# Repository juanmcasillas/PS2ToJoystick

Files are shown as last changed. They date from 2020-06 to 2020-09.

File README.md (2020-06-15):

# PS2ToJoystick

After trying to connect my old [EMS PS2 to PC adapter](http://www.hkems.com/product/ps2/ps2-usb2.htm) in Windows 10 without success, because there are no drivers available for Windows 10 x64; and the provided driver from Microsoft doesn't show the controller, I build this small PS2 to PC adapter, using an **arduino micro**, a **PS2 female connector** and some wire. And here you are!, **PS2ToJoystick** !.

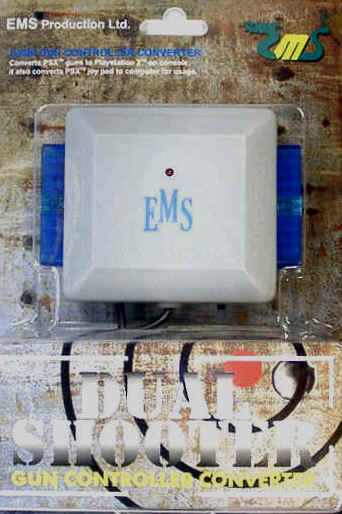
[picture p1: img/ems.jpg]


## Table Of Contents

1. [Project Features](#project-features)
2. [Part List](#part-list)
3. [Software](#software)
    1. [Arduino Setup](#arduino-setup)
    2. [Testing](#testing)
    3. [Multi](#multi)
4. [Electronics](#electronics)
    1. [Wiring](#wiring)
5. [Box Enclosure](#box-enclosure)
6. [X360 Controller](#x360-controller)

## Project Features

This project provides:

1. The hardware diagram to connect the PS2 connector to the arduino micro.
2. The software to map the PS2 Dualshock 2 gaming pad buttons and axis, to PC Joystick buttons.
3. The STL to 3D print a simple box to enclosure all.
4. The documentation to map the excellect [X360ce driver](https://github.com/x360ce/x360ce/releases) so the arduino is shown as an X360 PC Controller.

**NOTE**: Rumble (aka vibration) is not supported.

## Part List

1. Arduino Pro Micro clone (**ATmega32U4**) from [amazon](https://www.amazon.es/gp/product/B01MTU9GOB/.ref=ppx_yo_dt_b_asin_title_o04_s00?ie=UTF8&psc=1)
2. A female PS2 Dualshock 2 connector. I get one unironing it from the old EMS PS2 to PC Adapter.
3. Some wire.
4. A 3D Printer if you want to print the case.

## Software

The concept is very simple: map the PS2 Dualshock 2 buttons to an HID compatible device (joystick) so windows handles it with the standard driver. Arduino Leonardo (Micro) supports USB impersonation, so we can configure it as a Joystick, so problem solved.

My work is based on [this article](https://www.instructables.com/id/PS2-Wire-Controller-and-Arduino-control-LEDs/) and the excellect library created by [Bill Porter](http://www.billporter.info/2010/06/05/playstation-2-controller-arduino-library-v1-0/): [PS2X_lib](https://github.com/madsci1016/Arduino-PS2X/tree/master/PS2X_lib). A deep work on button protocol handling can be found [here](https://store.curiousinventor.com/guides/PS2). We need also the [Joystick Library](https://github.com/MHeironimus/ArduinoJoystickLibrary).

### Arduino Setup

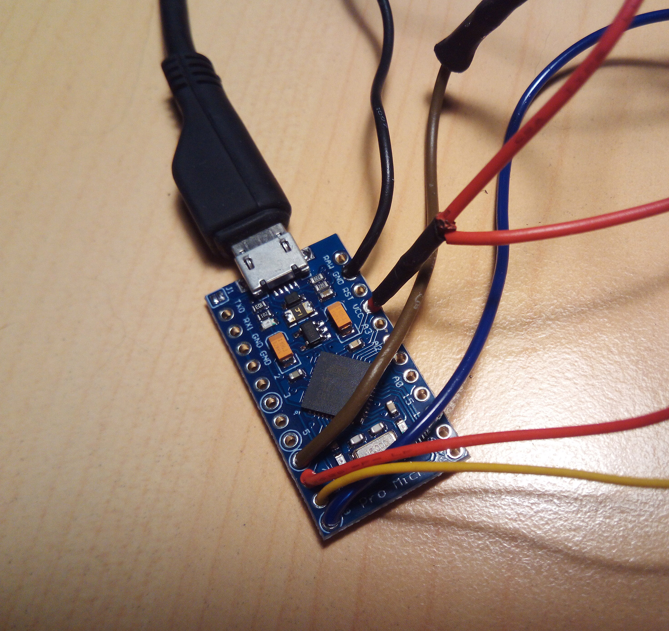
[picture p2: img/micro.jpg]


1. Download [PS2X_lib](https://github.com/madsci1016/Arduino-PS2X/tree/master/PS2X_lib) and install it in arduino libraries folder.
2. Download [ArduinoJoystickLibrary](https://github.com/MHeironimus/ArduinoJoystickLibrary) and install it in arduino libraries folder.
3. The Arduino Pro Micro selected uses an **ATmega32U4** microprocessor, so we have to choose in the board list
**Arduino Leonardo**. 
4. Select the USB port
5. Flash the `ps2joystick/ps2joystick.ino` sketch as usual.

NOTE: See [Multi](#multi) for an alternate sketch that support Keyboard & Joystick Handling at the same time.

### Testing

Just connect your Arduino Micro Clone in the PC with Windows 10, and open `Game Controllers`, you should have something like the following window:

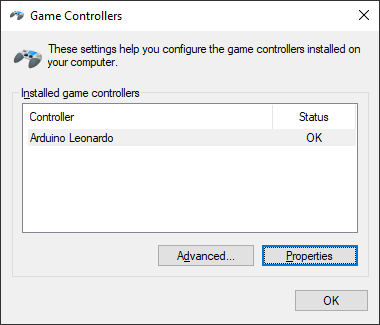
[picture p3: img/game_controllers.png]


Then click ond Properties, and check the buttons:

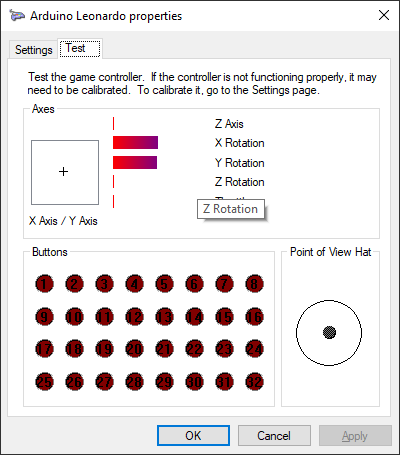
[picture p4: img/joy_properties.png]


* Left analog stick is mapped to X/Y Axis.
* Right analog stick is mapped to X/Y Rotation.

Button Mapping (on X360ce, we have to add '1' to the ID, see below)

|Name |Id |
|---|---:|
|JOY_CROSS |0 |
|JOY_CIRCLE |1 |
|JOY_SQUARE |2 |
|JOY_TRIANGLE |3 |
|JOY_L1 |4 |
|JOY_L2 |5 |
|JOY_L3 |6 |
|JOY_R1 |7 |
|JOY_R2 |8 |
|JOY_R3 |9 |
|JOY_SELECT |10 |
|JOY_START |11 |
|JOY_PAD_UP |12 |
|JOY_PAD_DOWN |13 |
|JOY_PAD_LEFT |14 |
|JOY_PAD_RIGHT |15 |

So you have a functional PS2 Dualshock 2 gaming pad working on your Windows 10, as a Joystick!. If you want to play modern games with the pad, you should read the section below [X360 Controller](#x360-controller)

### Multi

You can manage multiple HID devices from the same arduino Leonardo. Just load the required libraries, and work on. I need this support for mapping the [r6Pedals](https://github.com/juanmcasillas/r6pedals) project,
so I use only one arduino to handle the joystick and the custom button keyboards. instead flashing `ps2joystick/ps2joystick.ino` sketch, flash `ps2multi/ps2multi.ino`. This sketch maps:

|Arduino PIN |color |key |
|---|---|---:|
|4 |yellow  |e |
|5 |green |q |
|gnd |black | |
|gnd |black | |

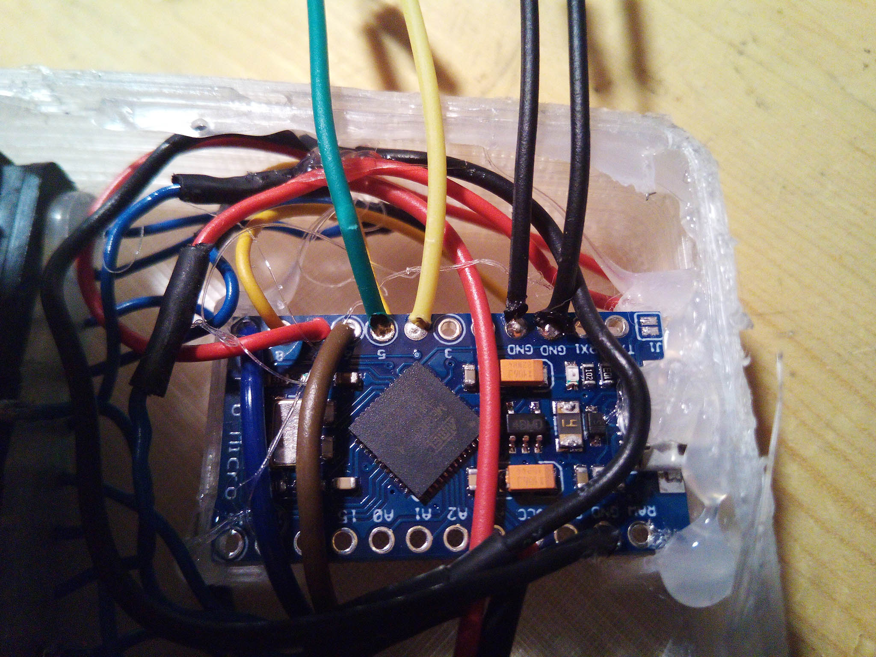
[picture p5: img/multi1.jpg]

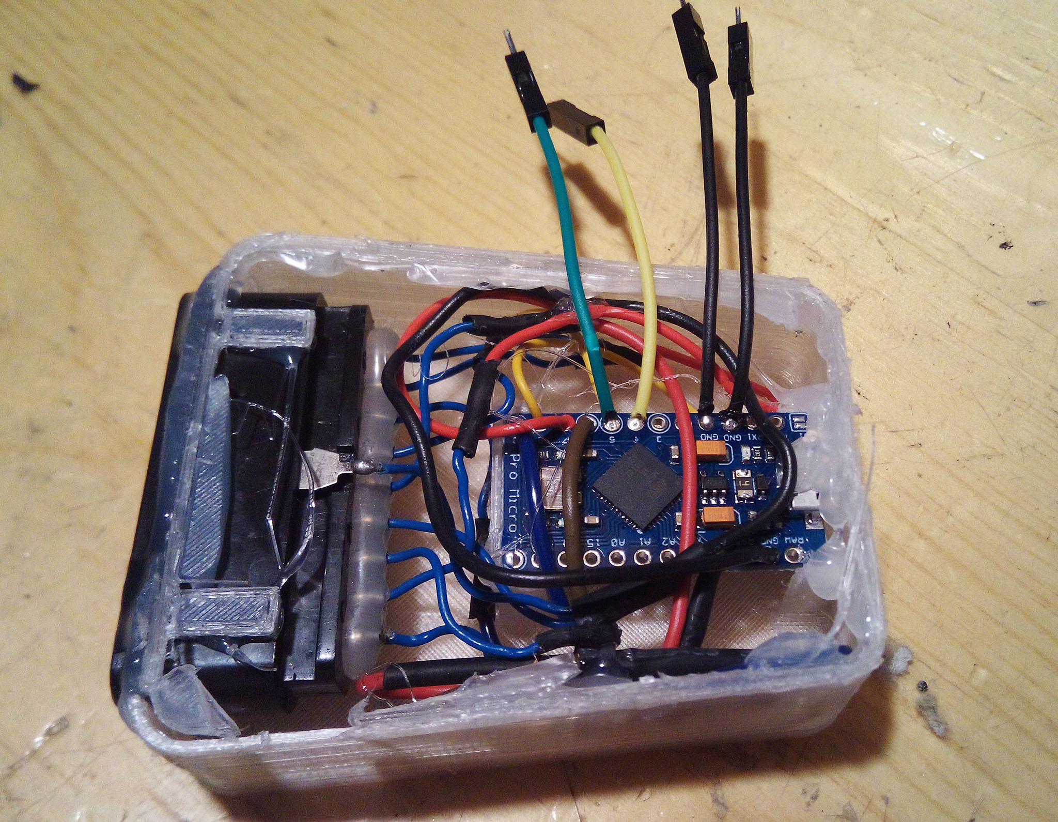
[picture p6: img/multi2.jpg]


## Electronics

Easy electronics. Just solder some wires (use pins if you want) following the next diagram

### Wiring

Female Socket (the opposite to DualShock 2 connector) (looking from FRONT)
```
\-------------------------/
 \ 1 2 3   4 5 6   7 8 9 /
  \---------------------/
```

|Dualshock PIN |color |function | arduino PIN|
|---|---|---|---:|
|1 |brown |DATA | (with pullup resistor 4.7KOhm) 6|
|2 |orange  |COMMAND  | 7|
|3 |grey |VIBRATION| |
|4 |black |GROUND | GND|
|5 |red |VCC | VCC|
|6 |yellow  |SELECT | 8|
|7 |blue |CLOCK | 9|
|8 |white |UNKNOWN  | |
|9 |green |ACK | |

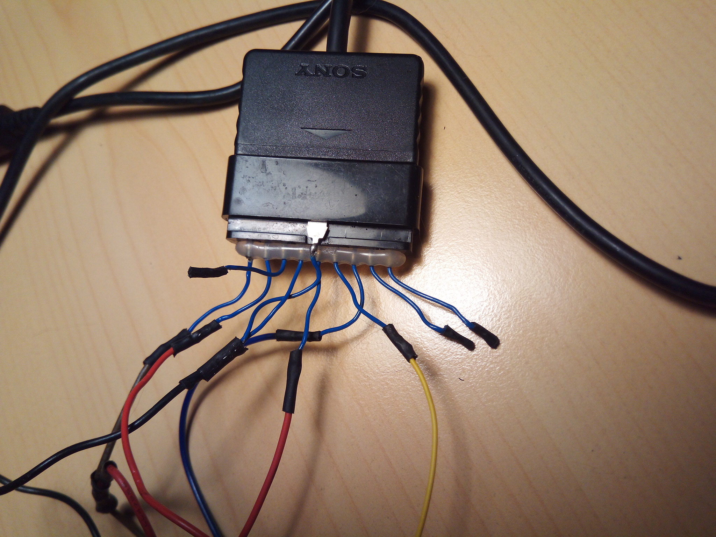
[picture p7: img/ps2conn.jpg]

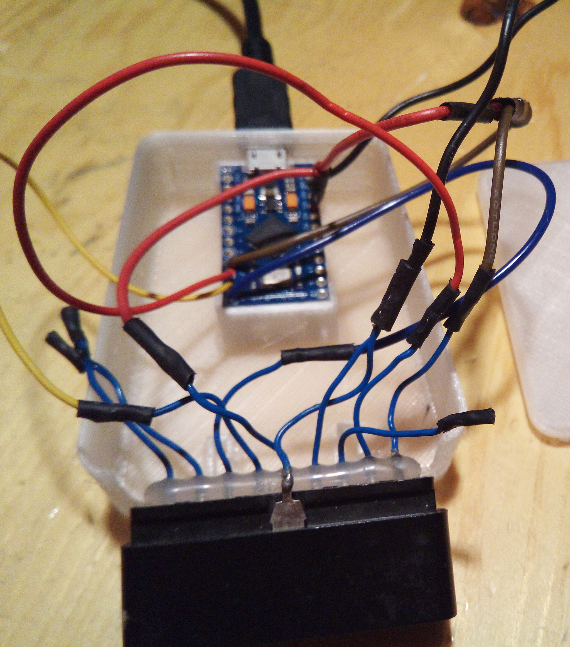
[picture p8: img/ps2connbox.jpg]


On **DualShock 2 PIN 1**, we need a pull up Resistor. This is the wiring diagram for that PIN:

```
                                ARDUINO PIN 6
                                    |
                                    |
 VCC -------------[ R 4.7KOhm ]-----+
                                    |
                                    |
                                DUALSHOCK 2 PIN 1 (BROWN)
```

In this picture, you can see the pull up resistor on the left side.
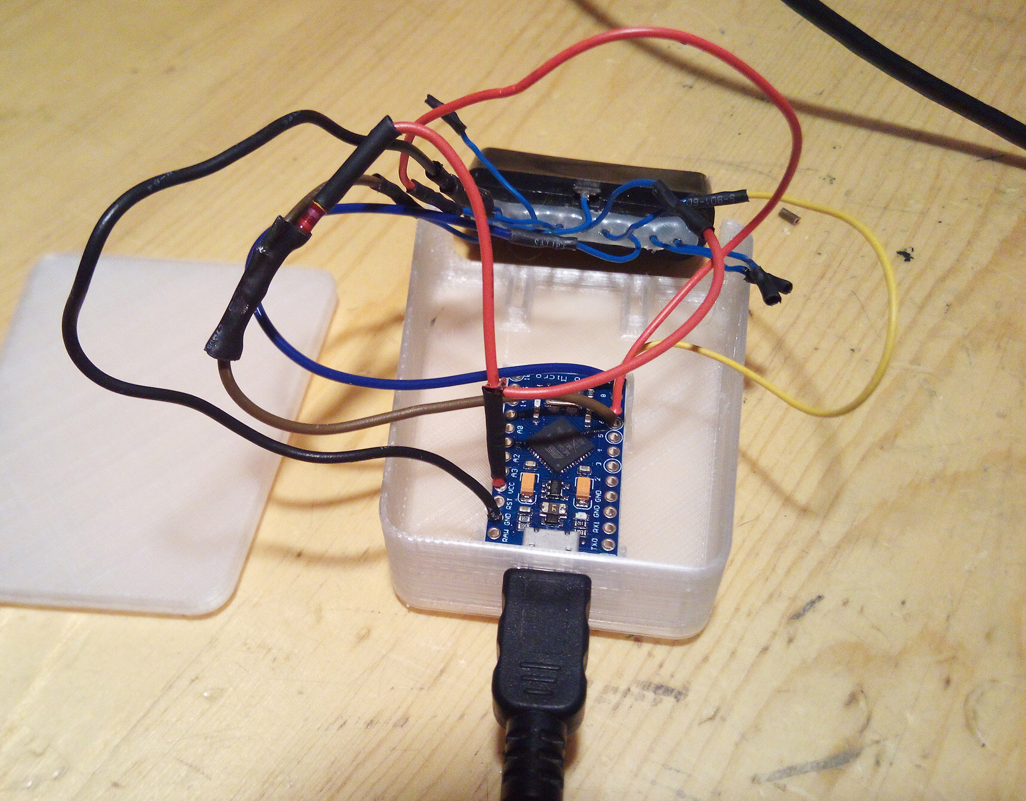
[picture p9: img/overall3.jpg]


## Box Enclosure

I provide a simple STL `3dprint/box.stl` file for the box enclosure, if you want to print it. The STL are ready positioned in the "right" way to be printed, so just print them as is. I use a Ender-3 Pro with Marlin Firwmare, and PLA, and get good results. It tooks about **2 hours 30 minutes** to print. I use CURA for slicing with the following major configuration settings:

|Variable |Value |
|---|---:|
|Layer Height| 0.21|
|Initial Layer Height| 0.32|
|Wall Thickness| 0.88|
|Wall Line count| 3|
|Top/Bottom Thickness| 0.92|
|top Thickness| 0.92|
|Top Layers| 5|
|bottom Thickness| 0.92|
|bottom Layers| 5|
|Top/Bottom pattern| lines|
|Horizontal expansion| 0|
|Infill density| 60%|
|Infill pattern| grid|
|Printing temperature| 190|
|Printing temperature initial layer| 195|
|Build plate temperature| 55|
|Build plate temperature initial layer| 75|
|Initial Layer flow| 100|
|Enable retraction| Checked|
|Retraction Distance| 6.5|
|Retraction Speed| 50|
|Print Speed| 50|
|Infill Speed| 50|
|Wall speed| 25|
|Top/Bottom speed| 25|
|Travel Speed| 150|
|Initial Layer Print Speed| 15|
|Initial Layer Travel Speed| 30|
|Combing mode| All|
|Avoid Supports when travelling| checked|
|Z Hop when retracted| checked|
|Enable Print cooling| checked|
|Fan Speed| 100|
|Initial Fan Speed| 0|
|Regular Fan Speed at Height| 0.72|
|Regular Fan Speed at Layer| 3|
|Generate Support| Checked|
|Support Placement| Everywhere|
|Support Overhang Angle| 47|
|Support Pattern| ZigZag|
|Support Density| 20|
|Support Z Distance| 0.2|
|Suport X/Y Distance| 0.88|
|User Towers| unchecked|
|Build plate adhesion type| None|
|Surface mode| Normal|
|Enable Bridge Settings| Checked|

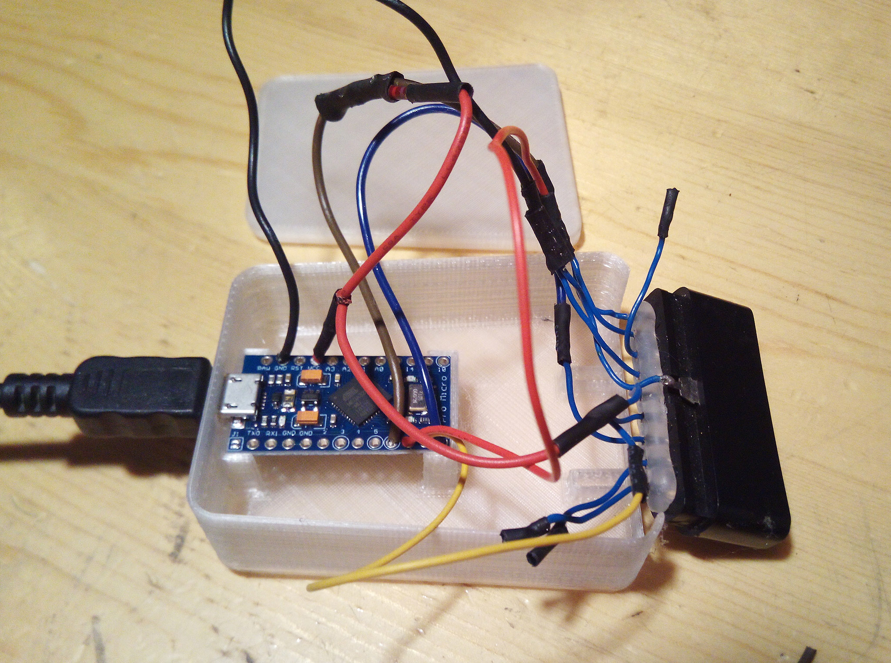
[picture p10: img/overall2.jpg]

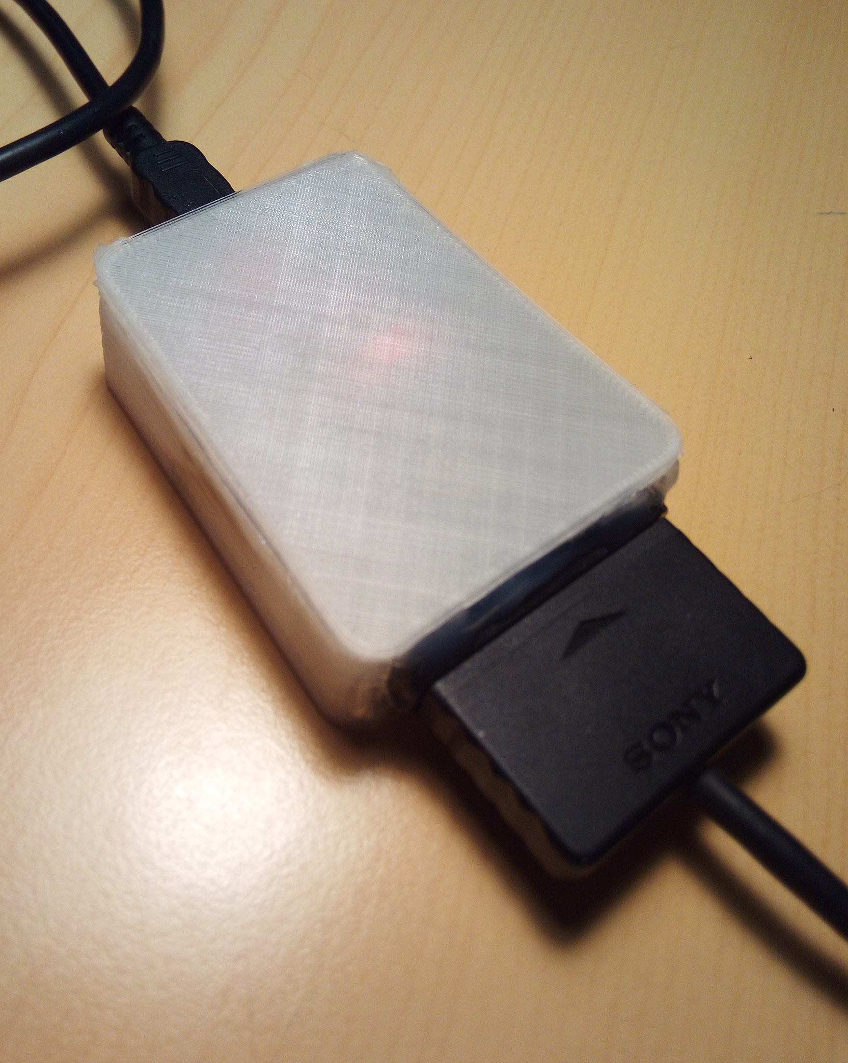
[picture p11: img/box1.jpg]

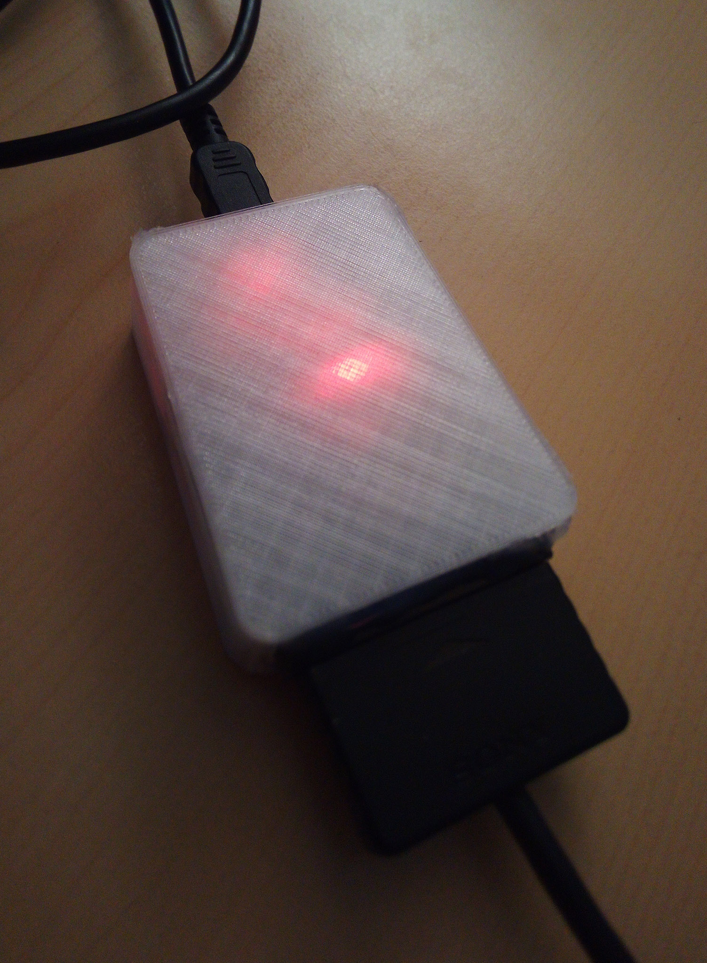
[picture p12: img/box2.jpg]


## X360 Controller

[X360ce](https://github.com/x360ce/x360ce) is a XBox 360 Contoller emulator: 

>"Xbox 360 Controller Emulator" allows your controller (gamepad, joystick, wheel, etc.) 
>to function as an Xbox 360 controller. For example, it lets you play games such 
>as "Grand Theft Auto" (GTA) or "Mafia II" using a Logitech Wheel.

We need to use the NEW version [alpha](https://github.com/x360ce/x360ce/releases/tag/4.10.0.0), no the stable one (they are very different) so [get the driver](https://github.com/x360ce/x360ce/releases/download/4.10.0.0/x360ce.zip) and install it.

I use this [excellect tutorial](https://steamcommunity.com/sharedfiles/filedetails/?id=875960196) to figure how to install it (this tutorial is for the old version). But the new version of X360ce requires a [sighly modified installation steps](https://github.com/x360ce/x360ce/wiki/Beta-Testing):

From their website:

>There is no need to place x360ce.exe inside the game folder. You can keep single copy of executable at one place (for >example: C:\Program Files\x360ce\x360ce.exe), because same virtual "Xbox 360 Controller" will be visible for all games >in Windows.

>Do not close "Xbox 360 Controller Emulator" during the game, just minimize it in order to reduce CPU use.

>Make sure your game is set to use XInput Devices. For example, in "Tom Clancy's Ghost Recon Wildlands" you have to set >OPTIONS -> CONTROLLER -> ENABLE CONTROLLER: ONLY GAMEPADS

### Install instructions (from their website):

1. Download latest Xbox 360 Controller Emulator (same file for 32-bit and 64-bit Windows) from: x360ce [4.x.x.x - Releases Page](https://github.com/x360ce/x360ce/releases)
2. Extract ZIP file and launch `x360ce.exe` file.
3. Enabling Virtual Drivers:
    1. `[Issues]` tab will start blinking it Virtual Drivers are missing.
    2. Press `[Issues]` tab and hit `[Install]` button to install Virtual Controller Drivers.
4. Mapping DirectInput Device:
    1. Connect your DirectInput Device to PC
    2. Select `[Controller 1]` tab and press `[Add..]` button.
    3. Select controller you want to map and press `[OK]` button.
    4. Click `"[x] Enable 1 Mapped Device"` checkbox inside `[Controller 1]` tab.
5. Configuring Mapping:
    1. Map buttons and axis by clicking on dropdowns, selecting `[Record]` and pressing on button or moving axis. 
    2. Hit `[Save]` button (at top right corner of application) when done.

6. Minimize `"Xbox 360 Controller Emulator"` in order to reduce CPU use. Note: Grey controller icon will be visible in tray.
7. Launch the game and see how it works.

#### Button Mappings for PS2 To Joystick in X360ce

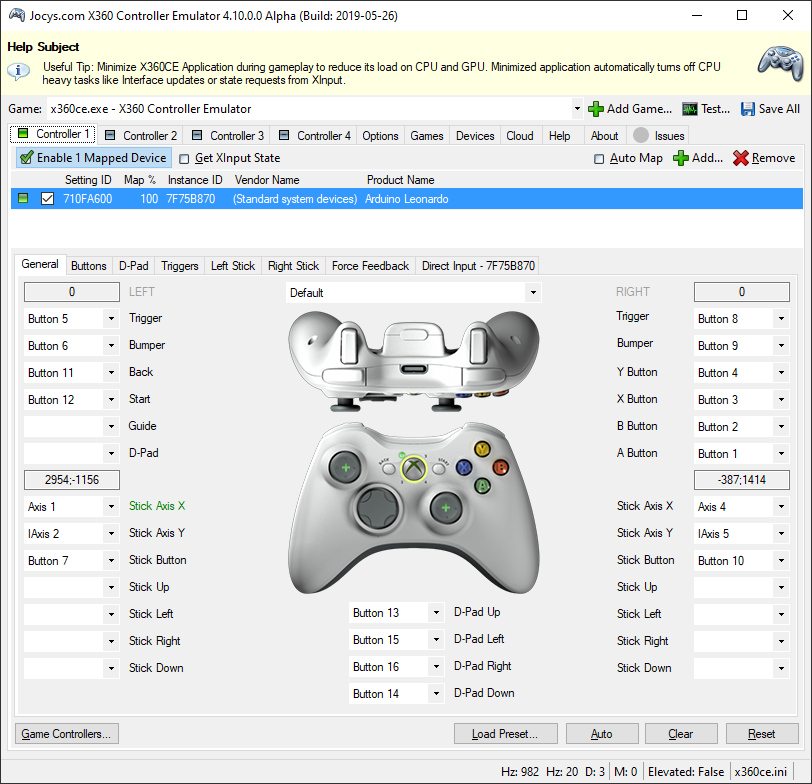
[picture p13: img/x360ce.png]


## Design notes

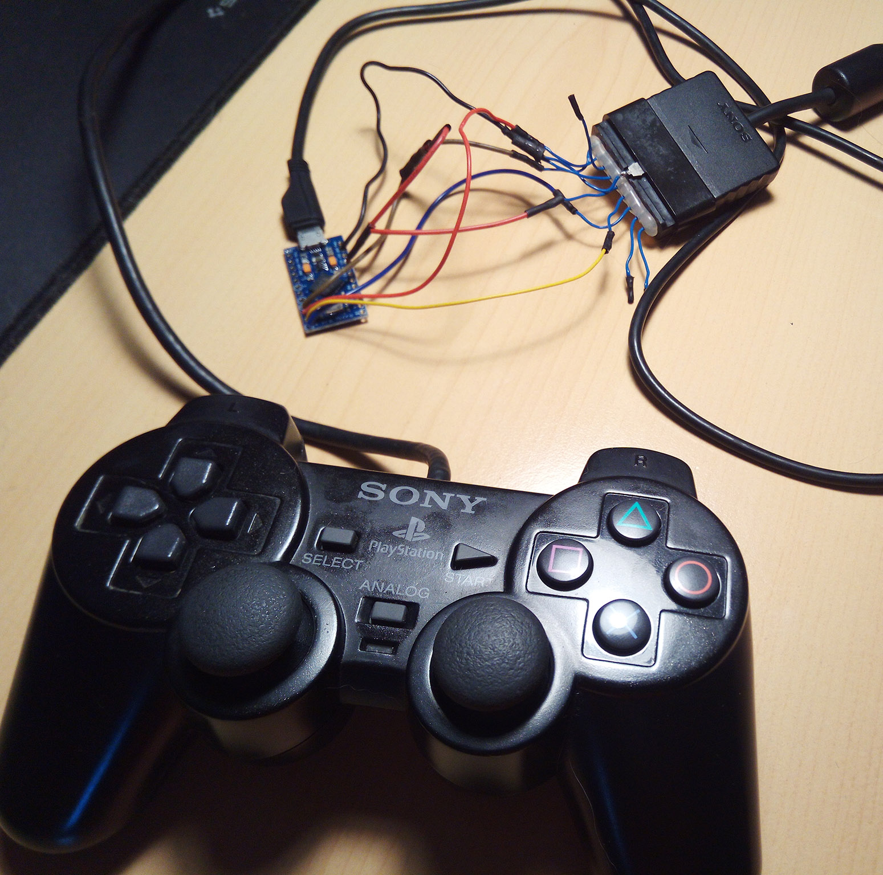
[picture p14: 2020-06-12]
img/overall1.jpg

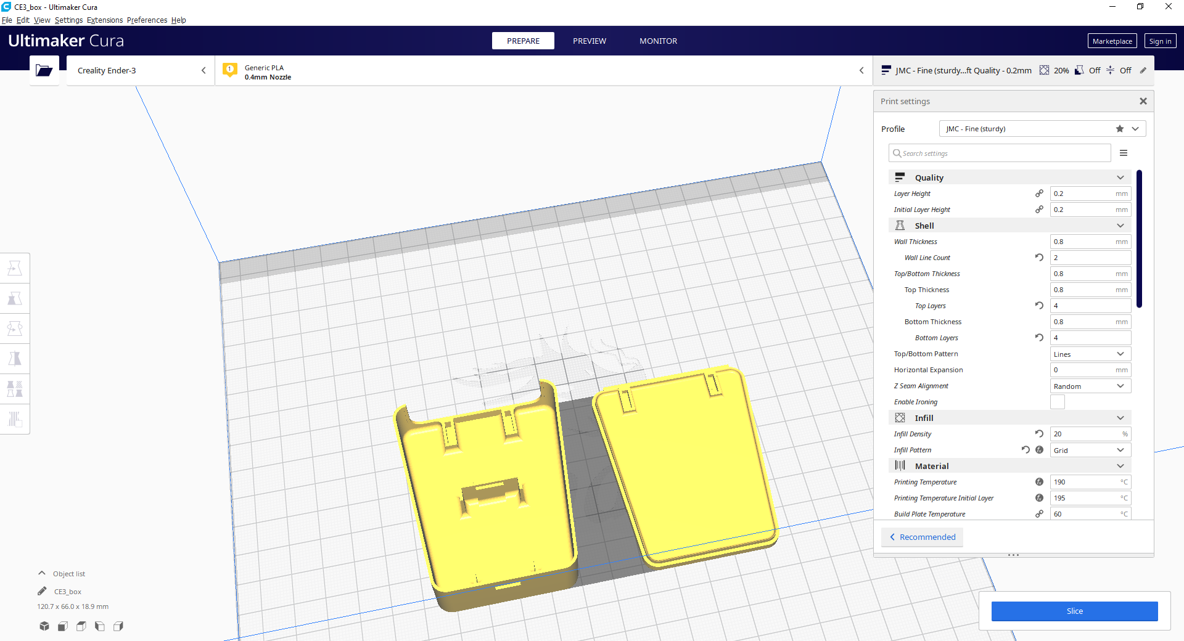
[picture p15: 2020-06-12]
img/stl.png

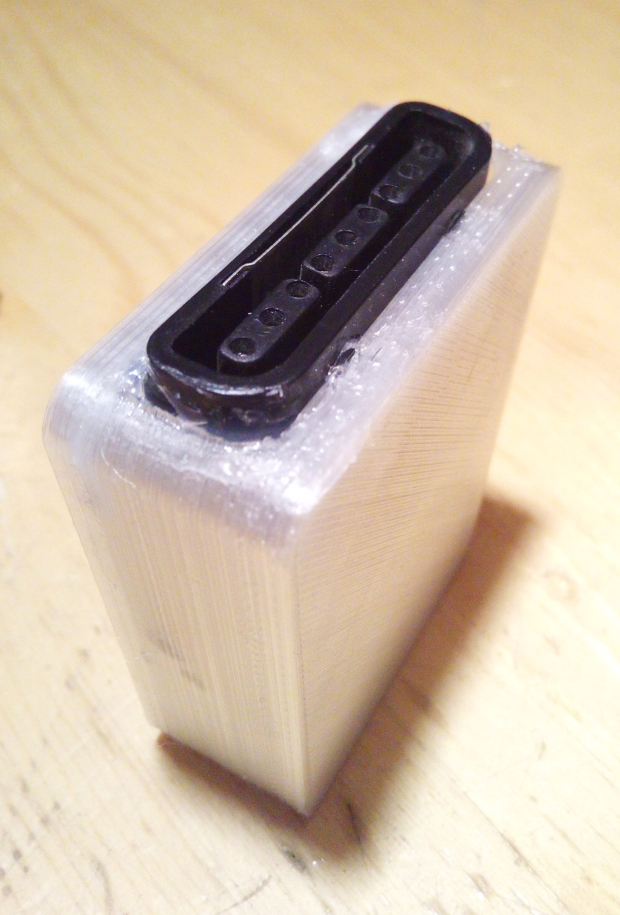
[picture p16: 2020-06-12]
img/boxps2conn.jpg

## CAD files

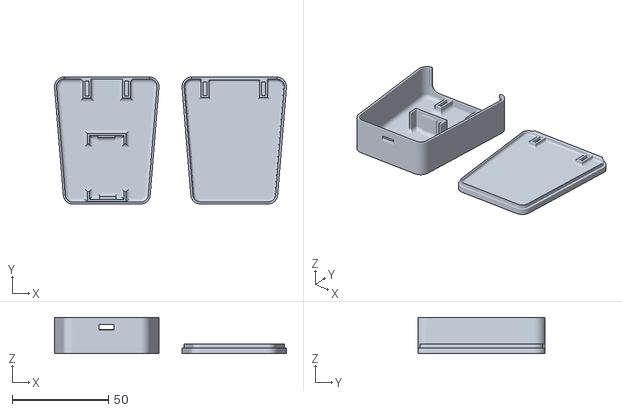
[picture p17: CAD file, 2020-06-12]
3dprint/box.stl
120.7 x 66.0 x 18.9

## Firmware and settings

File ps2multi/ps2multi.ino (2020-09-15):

// //////////////////////////////////////////////////////////////////////////
//
// PS2Multi
// (C) 2020 Juan M. Casillas <juanm.casillas@gmail.com>
//
// Creates a simple Arduino Micro (Leonardo) HID Joystick to manage the
// PS2 Dualshock 2 controller pad, because the current Win 10 Driver 
// doesn't support the old XP EMS Cheap PS2->PC Controllers
//
// 06-15-2020 Improved the code, so we can manage the R6Pedals (Keyboard HID)
// and PS2ToJoystick (Joystick HID) in the same arduino.
//
// //////////////////////////////////////////////////////////////////////////

#include <PS2X_lib.h>  //for v1.6
#include <Joystick.h>


#include <Keyboard.h>
#include <Bounce2.h>

#define BOUNCE_LOCK_OUT 1
#define BOUNCE_WAIT 1
#define BOUNCE_COUNT 1
#define NBUTTONS 2

int buttonPins[] = {
  5,//9, //Q button 1 (left)
  4,//8  //E button 2 (right)
};

char buttonPresets[] = { 
  'q', //button 1
  'e', //button 2
  };

boolean buttonPressed[NBUTTONS]; // Instantiate a Bounce object array to store each debouncer in
Bounce debouncers[NBUTTONS];     //Instantiate a counter array for each button to debounce count timer
int debounceCount[NBUTTONS];


// comment this to allow debug console
#define RELEASE
#define DELAY_TIME 20

#ifndef DBG_OUTPUT_PORT
#define DBG_OUTPUT_PORT Serial
#endif 

#ifndef RELEASE
#define DEBUGLOG(...) DBG_OUTPUT_PORT.print(__VA_ARGS__)
#define SERIAL_SPEED 115200
#else
#define DEBUGLOG(...)
#endif



//
// Set the Arduino PINS. I use an Arduino Pro Micro Clone (Leonardo)
// All the inputs are Digital Inputs. Remember that PS2_DAT requires
// a pull up resistor (4.7 KOhm)
//

#define PS2_DAT        6  //14    
#define PS2_CMD        7  //15
#define PS2_SEL        8  //16
#define PS2_CLK        9  //17

// Axis Limits
#define MIN_X           0
#define MAX_X           255
#define MIN_Y           0
#define MAX_Y           255

// Button Mapping
#define JOY_CROSS       0
#define JOY_CIRCLE      1
#define JOY_SQUARE      2
#define JOY_TRIANGLE    3

#define JOY_L1          4
#define JOY_L2          5
#define JOY_L3          6

#define JOY_R1          7
#define JOY_R2          8
#define JOY_R3          9

#define JOY_SELECT      10
#define JOY_START       11

#define JOY_PAD_UP      12
#define JOY_PAD_DOWN    13
#define JOY_PAD_LEFT    14
#define JOY_PAD_RIGHT   15

#define pressures   false
#define rumble      false

Joystick_ Joystick;
PS2X ps2x; 

int error = 0;
byte type = 0;
byte vibrate = 0;

void setup(){
 
#ifndef RELEASE 
  DBG_OUTPUT_PORT.begin(SERIAL_SPEED);
#endif  

    error = ps2x.config_gamepad(PS2_CLK, PS2_CMD, PS2_SEL, PS2_DAT, pressures, rumble);

    switch (error) {
        case 0:
            DEBUGLOG("Found Controller, configured successful ");
            break;
        case 1:
            DEBUGLOG("No controller found, check wiring, see readme.txt to enable debug. visit www.billporter.info for troubleshooting tips");
            break;
        case 2:
            DEBUGLOG("Controller found but not accepting commands. see readme.txt to enable debug. Visit www.billporter.info for troubleshooting tips");
            break;
        case 3:
            DEBUGLOG("Controller refusing to enter Pressures mode, may not support it. ");
            break;
    }

    type = ps2x.readType(); 
    switch(type) {
        case 0:
            DEBUGLOG("Unknown Controller type found ");
            break;
        case 1:
            DEBUGLOG("DualShock Controller found ");
            break;
        case 2:
            DEBUGLOG("GuitarHero Controller found ");
            break;
        case 3:
            DEBUGLOG("Wireless Sony DualShock Controller found ");
            break;
    }

    // left
    Joystick.setXAxisRange(MIN_X,MAX_X);
    Joystick.setYAxisRange(MIN_Y,MAX_Y);

    // right
    Joystick.setRxAxisRange(MIN_X,MAX_X);
    Joystick.setRyAxisRange(MIN_Y,MAX_Y);
    
    Joystick.begin();
    
    Joystick.setXAxis(int(MAX_X/2));
    Joystick.setYAxis(int(MAX_Y/2));

    Keyboard.begin();
    for (int i = 0; i < NBUTTONS; i++) {
        debouncers[i] = Bounce();
        //debounceCount[i] = 0;
        //pinMode(buttonPins[i],INPUT_PULLUP);
        (debouncers[i]).attach(buttonPins[i],INPUT_PULLUP);
        (debouncers[i]).interval(BOUNCE_WAIT);
        delay(100);
        buttonPressed[i] = false;
    }
}


void loop() {
    if(error == 0) {
      // manage gamepad
    
      ps2x.read_gamepad(); 
      
      if(ps2x.ButtonPressed(PSB_CIRCLE)) Joystick.pressButton(JOY_CIRCLE);
      if(ps2x.ButtonReleased(PSB_CIRCLE)) Joystick.releaseButton(JOY_CIRCLE);
  
      if(ps2x.ButtonPressed(PSB_CROSS)) Joystick.pressButton(JOY_CROSS);
      if(ps2x.ButtonReleased(PSB_CROSS)) Joystick.releaseButton(JOY_CROSS);
  
      if(ps2x.ButtonPressed(PSB_SQUARE)) Joystick.pressButton(JOY_SQUARE);
      if(ps2x.ButtonReleased(PSB_SQUARE)) Joystick.releaseButton(JOY_SQUARE);
  
      if(ps2x.ButtonPressed(PSB_TRIANGLE)) Joystick.pressButton(JOY_TRIANGLE);
      if(ps2x.ButtonReleased(PSB_TRIANGLE)) Joystick.releaseButton(JOY_TRIANGLE);
  
      if(ps2x.ButtonPressed(PSB_L1)) Joystick.pressButton(JOY_L1);
      if(ps2x.ButtonReleased(PSB_L1)) Joystick.releaseButton(JOY_L1);
  
      if(ps2x.ButtonPressed(PSB_L2)) Joystick.pressButton(JOY_L2);
      if(ps2x.ButtonReleased(PSB_L2)) Joystick.releaseButton(JOY_L2);
      
      if(ps2x.ButtonPressed(PSB_L3)) Joystick.pressButton(JOY_L3);
      if(ps2x.ButtonReleased(PSB_L3)) Joystick.releaseButton(JOY_L3);
  
  
      if(ps2x.ButtonPressed(PSB_R1)) Joystick.pressButton(JOY_R1);
      if(ps2x.ButtonReleased(PSB_R1)) Joystick.releaseButton(JOY_R1);
  
      if(ps2x.ButtonPressed(PSB_R2)) Joystick.pressButton(JOY_R2);
      if(ps2x.ButtonReleased(PSB_R2)) Joystick.releaseButton(JOY_R2);
      
      if(ps2x.ButtonPressed(PSB_R3)) Joystick.pressButton(JOY_R3);
      if(ps2x.ButtonReleased(PSB_R3)) Joystick.releaseButton(JOY_R3);
  
      if(ps2x.ButtonPressed(PSB_SELECT)) Joystick.pressButton(JOY_SELECT);
      if(ps2x.ButtonReleased(PSB_SELECT)) Joystick.releaseButton(JOY_SELECT);
  
      if(ps2x.ButtonPressed(PSB_START)) Joystick.pressButton(JOY_START);
      if(ps2x.ButtonReleased(PSB_START)) Joystick.releaseButton(JOY_START);
  
  
      Joystick.setXAxis(ps2x.Analog(PSS_LX));
      Joystick.setYAxis(ps2x.Analog(PSS_LY));
      Joystick.setRxAxis(ps2x.Analog(PSS_RX));
      Joystick.setRyAxis(ps2x.Analog(PSS_RY));
  
  
      // Direction Pad
      if(ps2x.ButtonPressed(PSB_PAD_UP)) Joystick.pressButton(JOY_PAD_UP);
      if(ps2x.ButtonReleased(PSB_PAD_UP)) Joystick.releaseButton(JOY_PAD_UP);
  
      if(ps2x.ButtonPressed(PSB_PAD_DOWN)) Joystick.pressButton(JOY_PAD_DOWN);
      if(ps2x.ButtonReleased(PSB_PAD_DOWN)) Joystick.releaseButton(JOY_PAD_DOWN);
  
      if(ps2x.ButtonPressed(PSB_PAD_RIGHT)) Joystick.pressButton(JOY_PAD_RIGHT);
      if(ps2x.ButtonReleased(PSB_PAD_RIGHT)) Joystick.releaseButton(JOY_PAD_RIGHT);
  
      if(ps2x.ButtonPressed(PSB_PAD_LEFT)) Joystick.pressButton(JOY_PAD_LEFT);
      if(ps2x.ButtonReleased(PSB_PAD_LEFT)) Joystick.releaseButton(JOY_PAD_LEFT);

    }

    // read and debounce buttons (for keyboard mapping)

    for (int j = 0; j < NBUTTONS; j++) { // iterate over each button (pin)
        
        (debouncers[j]).update();         //check current value
        /*
        int value = debouncers[j].read();
      
         if ( value == LOW ) {
            Keyboard.press(char(buttonPresets[j])); //Keyboard.write('1');
            buttonPressed[j] = true;
         } else {
            Keyboard.release(char(buttonPresets[j])); // if 0 then release button
            buttonPressed[j] = false;
         }
         */

 
         int value = (debouncers[j]).read();
         
        if ( value == LOW ) { // if button pressed
        
        // The button has been held down long enough and it hasn't been previously registered as pressed
        if(debounceCount[j] == BOUNCE_COUNT && buttonPressed[j] == false) { 
            Keyboard.press(char(buttonPresets[j])); //Keyboard.write('1');
            buttonPressed[j] = true;
            } else {
                if(debounceCount[j] < BOUNCE_COUNT) { 
                debounceCount[j] = debounceCount[j] + 1; 
                }
            }
            
        } else { //button is not pressed
            
            if(debounceCount[j] > 0) {
            debounceCount[j] = debounceCount[j] - 1; // keep decreasing count unless 0
            } else {
            Keyboard.release(char(buttonPresets[j])); // if 0 then release button
            buttonPressed[j] = false;
            }
        }
      
    }

    delay(DELAY_TIME);

}

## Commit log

2020-06-10 Fixed the Delay time
    [ps2joystick.ino]
2020-06-10 Added some wiring info
2020-06-10 Added the pullup resistor
2020-06-10 Added more documentation, and fixed some comments in main code
    [ps2joystick.ino]
2020-06-12 Added the documentation and files for PS2ToJoystick Added the doc for X360 Ce
    [box.stl]
2020-06-15 Added support for PS2Multi, so multiple HIDs are loaded in the same microcontroller. Now, Button inputs are passed as keyboard inputs (Q,E) and PS2Joystick is mapped as well.
2020-09-15 Fixed an issue when non connected the gamepad, the keyboard interface doesn't work. Currently fixed.
    [ps2multi.ino]
